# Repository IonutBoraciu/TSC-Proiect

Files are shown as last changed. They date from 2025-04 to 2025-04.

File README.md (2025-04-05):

# OpenBook, Boraciu Ionut-Sorin 335CA

# Description 

 OpenBook is an open-source, affordable e-book reader designed for mass production. The project focuses on accessibility, cost efficiency, and user control, providing a customizable reading experience with open hardware and software.

# Table of contents
1. [Description](#description)
2. [E-Book Reader Diagram](#e-book-reader-diagram)
3. [Bill of materials (BOM)](#bill-of-materials-bom)
4. [Hardware Functionality Description](#hardware-functionality-description)
5. [Estimated Power Consumption 🔋](#estimated-power-consumption-)
6. [Total estimated power consumtion ( assuming wifi active) 🔋](#total-estimated-power-consumtion--assuming-wifi-active-)
7. [Estimated battery life](#estimated-battery-life)
8. [ESP32-C6 Pin Usage](#esp32-c6-pin-usage)
9. [Pins explanation](#pins-explanation)
10. [Final Product](#final-product)

 # E-Book Reader Diagram

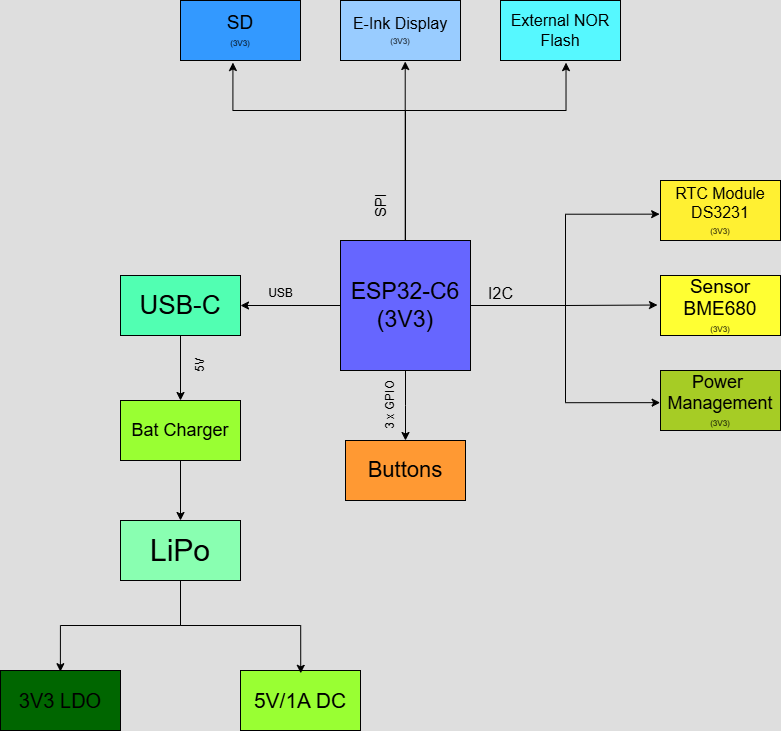
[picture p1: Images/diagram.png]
Diagram Image
 

 # Bill of materials (BOM)
 | 🛠 Component | 🔗 Link | 📄 Datasheet |
 |-------------|--------|------------|
 | 112A-TAAR-R03_ATTEND |[Comet](https://store.comet.srl.ro/Catalogue/Product/43497/) | [Datasheet](https://store.comet.bg/download-file.php?id=27596) |
 | 744043680IND | [Mouser](https://eu.mouser.com/ProductDetail/Wurth-Elektronik/744043680?qs=PGXP4M47uW6VkZq%252BkzjrHA%3D%3D) | [Datasheet](https://www.we-online.com/components/products/datasheet/744043680.pdf) |
 | ADAFRUIT_LEDCHIP | [SnapMagic](https://www.snapeda.com/parts/KP-1608SURCK/Kingbright/view-part/?ref=search&t=LED%200603) | [Datasheet](https://www.snapeda.com/parts/KP-1608SURCK/Kingbright/datasheet/) |
 | BD5229G-TR | [Component Search Engine](https://componentsearchengine.com/part-view/BD5229G-TR/ROHM%20Semiconductor) | [Datasheet](https://datasheet.datasheetarchive.com/originals/distributors/Datasheets_SAMA/f2b9741ef86007909f138d561a359946.pdf) |
 | BUTTON_CUSYOMV1 | [Panasonic](https://industry.panasonic.com/global/en/products/control/switch/light-touch/number/evqpuj02k) | [Datasheet](https://industry.panasonic.com/global/en/downloads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) |
 | CPH3225A | [SnapMagic](https://www.snapeda.com/parts/CPH3225A/Seiko+Instruments/view-part/?ref=eda) | [Datasheet](https://www.snapeda.com/parts/CPH3225A/Seiko%20Instruments/datasheet/) |
 | DS3231SN | [SnapMagic](https://www.snapeda.com/parts/DS3231SN%23/Analog+Devices/view-part/?ref=eda) | [Datasheet](https://www.snapeda.com/parts/DS3231SN%23/Analog%20Devices/datasheet/) |
 | EAGLE-LTSPICE_CC0402 | [Component Search Engine](https://componentsearchengine.com/part-view/CC0402MRX5R5BB106/YAGEO) | [Datasheet](https://componentsearchengine.com/Datasheets/2/CC0402MRX5R5BB106.pdf) |
 | ESP32-C6-WROOM-1-N8 | [SnapMagic](https://www.snapeda.com/parts/ESP32-C6-WROOM-1-N8/Espressif+Systems/view-part/?ref=eda) | [Datasheet](https://www.snapeda.com/parts/ESP32-C6-WROOM-1-N8/Espressif%20Systems/datasheet/) |
 | ESP32_WROVER_AVX | [Mouser](https://eu.mouser.com/ProductDetail/KYOCERA-AVX/SD0805S020S1R0?qs=jCA%252BPfw4LHbpkAoSnwrdjw%3D%3D) | [Datasheet](https://eu.mouser.com/datasheet/2/40/schottky-3165252.pdf) |
 | ESP32_WROVER_BME680_BME680 | [SnapMagic](https://www.snapeda.com/parts/BME680/Bosch/view-part/?welcome=home) | [Datasheet](https://www.snapeda.com/parts/BME680/Bosch%20Sensortec/datasheet/) |
 | ESP32_WROVER_EAGLE-LTSPICE_C | [Component Search Engine](https://componentsearchengine.com/part-view/CC0402MRX5R5BB106/YAGEO) | [Datasheet](https://componentsearchengine.com/Datasheets/2/CC0402MRX5R5BB106.pdf) |
 | ESP32_WROVER_EAGLE-LTSPICE_R | [Component Search Engine](https://componentsearchengine.com/part-view/R0402%201%25%20100%20K%20(RC0402FR-07100KL)/YAGEO) | [Datasheet](https://www.yageo.com/upload/media/product/products/datasheet/rchip/PYu-RC_Group_51_RoHS_L_12.pdf) |
 | ESP32_WROVER_SPARKFUN-DISCRETESEMI | [Component Search Engine](https://componentsearchengine.com/part-view/DMG2305UX-7/Diodes%20Incorporated) | [Datasheet](https://www.diodes.com//assets/Datasheets/DMG2305UX.pdf) |
 | ESP32_WROVER_SPARKFUN-IC-POWER_SOT23-5 | [Mouser](https://eu.mouser.com/ProductDetail/Microchip-Technology/MCP73831T-2ACI-OT?qs=yUQqVecv4qvbBQBGbHx0Mw%3D%3D) | [Datasheet](https://eu.mouser.com/datasheet/2/268/MCP73831_Family_Data_Sheet_DS20001984H-3441711.pdf) |
 | ESP32C6_VARISTORCN1812 | [Mouser](https://ro.mouser.com/ProductDetail/EPCOS-TDK/B72520T0350K062?qs=dEfas%2FXlABIszF52uu7vrg%3D%3D) | [Datasheet](https://www.tdk-electronics.tdk.com/inf/75/db/CTVS_14/Surge_protection_series.pdf) |
 | FH34SRJ24S05SH99 | [Component Search Engine](https://componentsearchengine.com/part-view/FH34SRJ-24S-0.5SH(99)/Hirose) | [Datasheet](https://www.hirose.com/en/product/document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) |
 | MAX17048G+T10 | [SnapMagic](https://www.snapeda.com/parts/MAX17048G+T10/Analog+Devices/view-part/?ref=eda) | [Datasheet](https://www.snapeda.com/parts/MAX17048G+T10/Analog%20Devices/datasheet/) |
 | MBR0530 | [Mouser](https://ro.mouser.com/ProductDetail/KYOCERA-AVX/SD0805S020S1R0?qs=jCA%252BPfw4LHbpkAoSnwrdjw%3D%3D) | [Datasheet](https://ro.mouser.com/datasheet/2/40/schottky-3165252.pdf) |
 | PGB1010603MR | [SnapMagic](https://www.snapeda.com/parts/PGB1010603MR/Littelfuse/view-part/?ref=eda) | [Datasheet](https://www.snapeda.com/parts/PGB1010603MR/Littelfuse%20Inc./datasheet/) |
 | QWIIC_CONNECTORJS | [Mouse](https://eu.mouser.com/ProductDetail/Adafruit/4208?qs=PzGy0jfpSMtbScLbr0L5dw%3D%3D) | [Datasheet](https://www.youtube.com/watch?v=Z6ACqvqwDWE) |
 | SAMACSYS_PARTS_USB4110-GF-A | [Component Search Engine](https://componentsearchengine.com/part-view/USB4110-GF-A/GCT%20(GLOBAL%20CONNECTOR%20TECHNOLOGY)) | [Datasheet](https://gct.co/files/drawings/usb4110.pdf) |
 | SI1308EDL-T1-GE3 | [Component Search Engine](https://componentsearchengine.com/part-view/SI1308EDL-T1-GE3/Vishay) | [Datasheet](https://componentsearchengine.com/Datasheets/1/SI1308EDL-T1-GE3.pdf) |
 | SJ | [GrabCAD](https://grabcad.com/library/solder-jumpers-1) | [Datasheet](https://www.youtube.com/watch?v=Z6ACqvqwDWE) |
 | USBLC6-2SC6Y | [SnapMagic](https://www.snapeda.com/parts/USBLC6-2SC6Y/STMicroelectronics/view-part/?ref=eda) | [Datasheet](https://www.snapeda.com/parts/USBLC6-2SC6Y/STMicroelectronics/datasheet/) |
 | W25Q512JVEIQ | [SnapMagic](https://www.snapeda.com/parts/W25Q512JVEIQ/Winbond+Electronics/view-part/?ref=eda) | [Datasheet](https://www.snapeda.com/parts/W25Q512JVEIQ/Winbond%20Electronics/datasheet/) |
 | XC6220A331MR-G | [Component Search Engine](https://componentsearchengine.com/part-view/XC6220A331MR-G/Torex) | [Datasheet](https://product.torexsemi.com/system/files/series/xc6220.pdf) |

# Hardware Functionality Description

### 1. Battery 🔋
 Model: CELLEVIA BATTERIES LP584174 <br>
 Specifications: 3.7V, 1800mAh  <br>
 Functionality: It is rechargeable battery, designed for portable electronic devices. It provides a stable power supply, high energy density, and a lightweight form factor. Ideal for IoT devices, wearables, embedded systems, and battery powered applications, it ensures reliable performance with a long cycle life.

 ### 2. ESP32-C6 📡
 Model: ESP32-C6-WROOM-1 <br>
 Specifications:
  * 2.4 GHz Wi-Fi 6 (802.11 ax)
  *  Bluetooth® 5 (LE) with Long Range support
  *  Zigbee and Thread(802.15.4) for low-power mesh networking  <br>
  
  Functionality: The ESP32-C6-WROOM-1 is the central controller of the project, handling all communication, control, and processing

  ### 3. E-Paper Display 📺
  Model: 7.5inch e-Paper V2 <br>
  Specifications: resolution : 800 x 480, weight ~ 44 g <br>
  Functionality: The 7.5-inch e-Paper V2 display provides a high contrast, low power visual output suitable for battery-powered applications. Unlike traditional displays, it retains content without power, making it ideal for low energy and always on applications.

 ### 4. BME688 🌡️
 Interface: I2C <br>
 Specifications:
  * Gas Sensor: Detects volatile organic compounds, carbon monoxide, hydrogen, and other gases
  * Humidity Sensor: 0–100% RH, accuracy ±3%
  * Temperature Sensor: -40°C to 85°C, accuracy ±0.5°C
  * Pressure Sensor: 300–1100 hPa, accuracy ±0.6 hPa <br>
  
 Functionality: The BME688 is an advanced environmental sensing module, providing real-time monitoring of air quality, humidity, temperature, and pressure.

 ### 5. SD Card 💾
 Interface: SPI <br>
 Functionality: it serves as expandable storage, allowing users to store a large collection of e-books, documents, and other files beyond the device's internal memory

 ### 6. RTC ⏰
 Interface: I2C <br>
 Functionality: A real-time clock (RTC) keeps track of the correct time and date, even when the device is off. It helps manage power saving features, timestamps activities like reading progress, supports reminder functions, updates time-sensitive content, and ensures proper synchronization with other devices or platforms.

 ### 7. MCP73831T ♻️🔋
 Interface: USB-C <br>
 Functionality: The MCP73831T is a compact lithium-ion and lithium-polymer battery charger IC. It features low power consumption, precharge and fast charge modes, thermal regulation, and overvoltage protection, making it ideal for portable devices.

 ### 8. External NOR Flash 64MB 🎞️
 Interface: SPI <br>
 Functionality:  non-volatile memory storage that provides 64MB of data storage. It's commonly used in embedded systems and devices for storing firmware, code, or other critical data, offering fast read speeds and reliable data retention even without power.

 ### 9. LDO Voltage Regulator ⚡
 Functionality: voltage regulator that provides a stable output voltage with minimal difference between the input and output voltages.

 ### 10. Test Pads 📝
 Functionality: deubbing and testing outputs from certain components.

 ### 11. Qwiic ✅
 Functionality: easy addition of modules through I2C and SPI.

 # Estimated Power Consumption 🔋

 ### 1. Battery (CELLEVIA BATTERIES LP584174) 🔋
  * Its power consumption depends on the load it is powering. The maximum discharge current would be around 1.8A (1800mAh)
### 2. ESP32-C6 📡
  * Wi-Fi transmission: ~200mA
  * Idle mode: ~50mA
  * Deep sleep: ~10mA
### 3. E-Paper Display 📺
  * During content update: ~30-50mA
  * Idle (static content): ~0mA (only power used for maintaining the display)
### 4. BME688 🌡️
 * Active sensing: ~2.7mA
 * Idle mode: ~0.5mA (depends on the sleep settings)
### 5. SD Card 💾
 * Typical: ~10-15 mA
### 6. RTC ⏰
* Active mode: 1- 2 mA
### 7. MCP73831T ♻️🔋
*  Minimal power consumption
### 8. External NOR Flash 64MB 🎞️
* Active read/write: ~10-20mA
* Idle: <1mA
### 9. LDO Voltage Regulator ⚡
 * Idle mode: ~1-10mA (depends on the output load)
### 10. Test Pads 📝
* Minimal power consumption, essentially 0mA unless active signals are being tested.
### 11. Qwiic ✅
* Active communication: ~5-10mA (depends on the connected module)

# Total estimated power consumtion ( assuming wifi active) 🔋

 | 🛠 Component | Power estimation 🔋
 |-------------|--------|
 | ESP32-C6 | 200 mA |
 | E-Paper Display | 50 mA |
 | BME688 | 2.7 mA |
 | SD Card | 15 mA |
 | RTC | 2 mA |
 | External NOR Flash | 20 mA |
 | LDO Voltage Regulator | 10 mA |
 | Qwiic | 10 mA |

Total = 200mA + 50mA + 2.7mA + 15mA + 2mA + 20mA + 10mA + 10mA = 309.7mA

# Estimated battery life

**Battery life = 1800 mAh / 309.7 mA = 5.81 hours**

# ESP32-C6 Pin Usage

## Power connections 🔋
* Pin 2 ( 3V3) - provides 3.3V to the ESP32-C6
* Ground ( bottom-right pin) - provides ground connection

## Reset and Boot 🔁
* Pin 3 ( Reset) - manual reset pin
* Pin 15 ( IO/BOOT) - boot mode selection, pulled down by a 10K resistor

## I2C 📡
* Pin 8 ( INT_RTC) - interrupt signal from RTC
* Pin 16 ( RTC_RST) - reset for RTC
* Pin 18 ( I2C_PW) - power enable signal for I2C devices
* Pin 20 ( SDA) - data line for I2C comms
* Pin 21 ( SCL) - clock line for I2C comms

## SPI 🛰️
* Pin 4 ( SS_SD) - slave select for SD card
* Pin 7 ( SCK) - Serial clock used for synchronizing SPI comms
* Pin 10 ( MOSI) - Master Out Slave In, sending data to components
* Pin 11 ( EPD_CS) - chip select for e-paper display
* Pin 12 ( FLASH_CS) - chip select for flash memory
* Pin 27 ( MISO)  - Master In Slave Out, used for reading data from components

## E-Paper Display Control Signals 🖥️
* Pin 5 ( EPD_DC) - data control for E-Paper Display
* Pin 19 ( EPD_3V3_C) - enable pin for EPD power
* Pin 21 ( EPD_RST) - reset pin for E-Paper Display
* Pin 26 ( EPD_BUSY) - indicates when E-Paper Display is busy

## USB 🔌
* Pin 13 ( USB_D-) + Pin 14 ( USB_D+) - differential data lines for USB comms

## UART 🔧
* Pin 24 ( RX) - UART receive pin
* Pin 25 ( TX) - UART transmit pin

## Others ⚙️
* Pin 23 ( IO_CHANGE)  - interrupt or status for external components

# Pins explanation

* SPI (Serial Peripheral Interface) is used for high speed comms with the Flash and E-Paper Display.
* I2C low speed comms with sensor ( RTC).
* UART pins ( TX, RX) debugging and external serial comms.
* Dedicated control pins ( EPD_BUSY, EPD_DC) ensure efficient E-Paper operation.

# Final Product
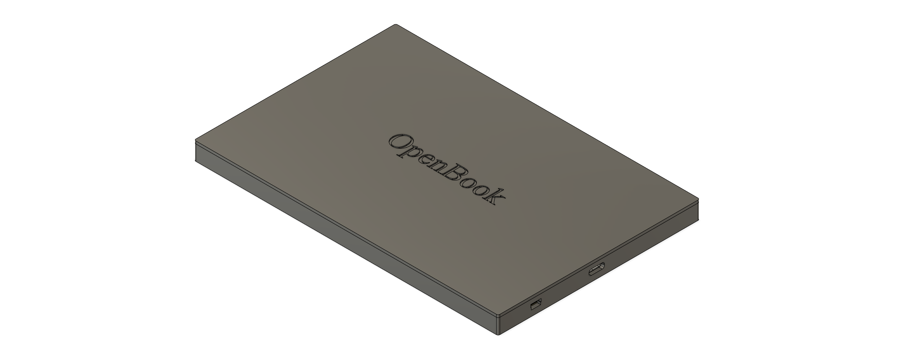
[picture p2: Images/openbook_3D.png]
3D Image
 
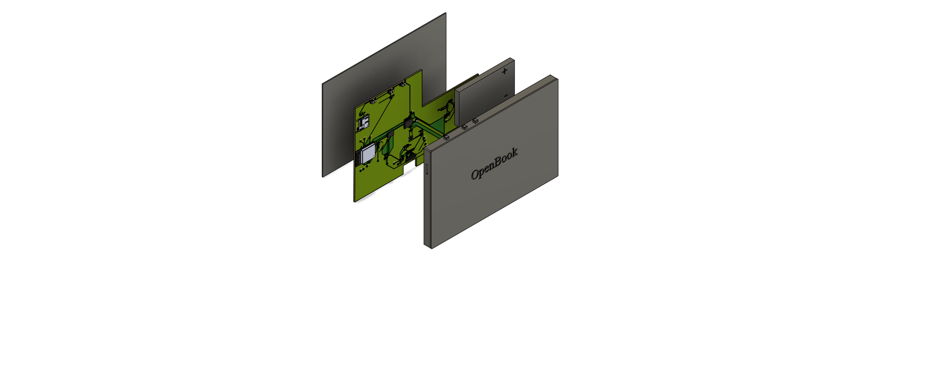
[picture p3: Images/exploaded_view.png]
Exploaded Image


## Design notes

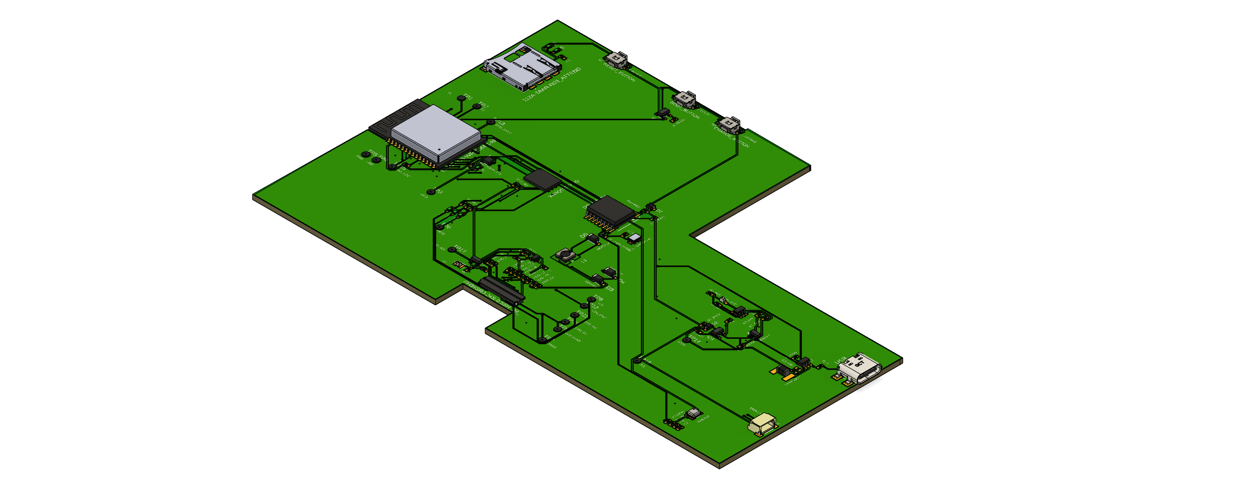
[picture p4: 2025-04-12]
Images/3D_board.png

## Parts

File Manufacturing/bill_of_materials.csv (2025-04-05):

Qty | Value | Device | Package | Parts | Description | ARROW_PART_NUMBER | ARROW_PRICE-STOCK | AVAILABILITY | CHECK_PRICES | COPYRIGHT | DESCRIPTION | HEIGHT | MANUFACTURER_NAME | MANUFACTURER_PART_NUMBER | MF | MFR_NAME | MOUSER_PART_NUMBER | MOUSER_PRICE-STOCK | MOUSER_TESTING_PART_NUMBER | MOUSER_TESTING_PRICE-STOCK | MP | PACKAGE | POPULARITY | PRICE | PROD_ID | PURCHASE-URL | SNAPEDA_LINK | SPICEMODEL | SPICEPREFIX | TP_SIGNAL_NAME | VALUE
1 |  | ADAFRUIT_LEDCHIP-LED0603 | ADAFRUIT_CHIP-LED0603 | CHG_LED | LED
1 |  | SJ | SJ | SJ1 | SMD solder JUMPER |  |  |  |  |  |  |  |  |  |  |  |  |  |  |  |  |  | 3
1 | 0.1uF/50V | ESP32_WROVER_EAGLE-LTSPICE_C | ESP32_WROVER_EAGLE-LTSPICE_C0402 | EPD_C5 | CAPACITOR, European symbol
1 | 0.47 | ESP32_WROVER_EAGLE-LTSPICE_R | ESP32_WROVER_EAGLE-LTSPICE_R0402 | R3 | RESISTOR, European symbol
1 | 100k | ESP32_WROVER_EAGLE-LTSPICE_R | ESP32_WROVER_EAGLE-LTSPICE_R0402 | R1_PWRUSB | RESISTOR, European symbol
1 | 100nF | EAGLE-LTSPICE_CC0402 | EAGLE-LTSPICE_C0402 | C6 | CAPACITOR, European symbol |  |  |  |  |  |  |  |  |  |  |  |  |  |  |  |  |  |  |  |  |  |  | NONE | C
7 | 100nF | ESP32_WROVER_EAGLE-LTSPICE_C | ESP32_WROVER_EAGLE-LTSPICE_C0402 | C2, C4, C4_USB, C8, C9, C10, C_DELAY | CAPACITOR, European symbol
1 | 100uF TANT | ESP32_WROVER_EAGLE-LTSPICE_C | ESP32_WROVER_EAGLE-LTSPICE_C0402 | C3 | CAPACITOR, European symbol
15 | 10K | ESP32_WROVER_EAGLE-LTSPICE_R | ESP32_WROVER_EAGLE-LTSPICE_R0402 | R1-PINH, R1_PINH1, R2-PINH, R2-PINH1, R4, R5, R6, R7, R8, R9, R10, R_BOOT, R_CHANGE, R_CL1, R_RESET | RESISTOR, European symbol
1 | 10k | ESP32_WROVER_EAGLE-LTSPICE_R | ESP32_WROVER_EAGLE-LTSPICE_R0402 | R1 | RESISTOR, European symbol
1 | 10uF | ESP32_WROVER_EAGLE-LTSPICE_C | ESP32_WROVER_EAGLE-LTSPICE_C0402 | C7 | CAPACITOR, European symbol
1 | 112A-TAAR-R03_ATTEND | 112A-TAAR-R03_ATTEND | 112ATAARR03ATTEND | J4 | Micro SD Card Socket, Push-Push Type, Top Mount, SMT, H=1.83mm, 10u |  |  |  |  |  | Micro SD Card Socket | Push-Push Type | Top Mount | SMT | H=1.83mm | 10u | 1.9mm | ATTEND | 112A-TAAR-R03 ATTEND
1 | 15 | ESP32_WROVER_EAGLE-LTSPICE_R | ESP32_WROVER_EAGLE-LTSPICE_R0402 | R_CAPACITOR | RESISTOR, European symbol
1 | 1uF | EAGLE-LTSPICE_CC0402 | EAGLE-LTSPICE_C0402 | C5 | CAPACITOR, European symbol |  |  |  |  |  |  |  |  |  |  |  |  |  |  |  |  |  |  |  |  |  |  | NONE | C
9 | 1uF/50V | ESP32_WROVER_EAGLE-LTSPICE_C | ESP32_WROVER_EAGLE-LTSPICE_C0402 | EPD_C1, EPD_C2, EPD_C6, EPD_C7, EPD_C8, EPD_C9, EPD_C10, EPD_C11, EPD_C12 | CAPACITOR, European symbol
1 | 2.2 | ESP32_WROVER_EAGLE-LTSPICE_R | ESP32_WROVER_EAGLE-LTSPICE_R0402 | R2 | RESISTOR, European symbol
1 | 200 | ESP32_WROVER_EAGLE-LTSPICE_R | ESP32_WROVER_EAGLE-LTSPICE_R0402 | R1_BAT | RESISTOR, European symbol
1 | 2k | ESP32_WROVER_EAGLE-LTSPICE_R | ESP32_WROVER_EAGLE-LTSPICE_R0402 | R2_BAT | RESISTOR, European symbol
5 | 4.7uF | ESP32_WROVER_EAGLE-LTSPICE_C | ESP32_WROVER_EAGLE-LTSPICE_C0402 | C1_BAT, C1_BAT1, C1_BAT2, C2_BAT, C5_USB | CAPACITOR, European symbol
1 | 4.7uF/25V | ESP32_WROVER_EAGLE-LTSPICE_C | ESP32_WROVER_EAGLE-LTSPICE_C0402 | C1 | CAPACITOR, European symbol
2 | 5k1 | ESP32_WROVER_EAGLE-LTSPICE_R | ESP32_WROVER_EAGLE-LTSPICE_R0402 | R2-USB, R_J2 | RESISTOR, European symbol
1 | 68uH | 744043680IND_4828-WE-TPC_WRE | IND_4828-WE-TPC_WRE | L1 |  |  |  |  |  | Copyright (C) 2024 Ultra Librarian. All rights reserved. |  |  |  | 744043680 |  | Wurth Electronics
1 | BD5229G-TR | BD5229G-TR | SOT95P280X125-5N | IC1 | Voltage Detector with Adjustable Delay Time: CMOS processes are utilized to develop high precision, low current consumption CMOS reset ICs that allow arbitrary setting of the delay time. The extensive lineup includes both Nch Open Drain and CMOS output types in a wide range of detection voltages (from 2.3V to 6.0V, in 0.1V steps), enabling selection of the ideal solution based on customer requirements. In addition, the entire series is of course both lead-free and RoHS-compliant. |  |  |  |  |  | Voltage Detector with Adjustable Delay Time: CMOS processes are utilized to develop high precision | low current consumption CMOS reset ICs that allow arbitrary setting of the delay time. The extensive lineup includes both Nch Open Drain and CMOS output types in a wide range of detection voltages (from 2.3V to 6.0V | in 0.1V steps) | enabling selection of the ideal solution based on customer requirements. In addition | the entire series is of course both lead-free and RoHS-compliant. | 1.25mm | ROHM Semiconductor | BD5229G-TR |  |  | 755-BD5229G-TR | https://www.mouser.co.uk/ProductDetail/ROHM-Semiconductor/BD5229G-TR?qs=4kLU8WoGk0vvnhrrYwdszw%3D%3D
1 | BME688 | ESP32_WROVER_BME680_BME680 | ESP32_WROVER_BME680_PSON80P300X300X100-8N | SENSOR2 | Integrated Environmental Unit |  |  | Unavailable |  |  | Integrated Environmental Unit |  |  |  | Bosch Sensortec |  |  |  |  |  | BME680 | LGA-8 Bosch Tools |  | None
1 | BOOT_BUTTON | BUTTON_CUSYOMV12_MYBUTTON | MYBUTTON | U$2
1 | CHANGE_BUTTON | BUTTON_CUSYOMV12_MYBUTTON | MYBUTTON | U$3
1 | CPH3225A | CPH3225A | CAPCP3225X100N | C10_SUPERCAP | Cap 0.011F 3.3V 1210 Flat Check availability |  |  | Not in stock | https://www.snapeda.com/parts/CPH3225A/Seiko+Instruments/view-part/?ref=eda |  | 11 mF (EDLC) Supercapacitor 3.3 V 1210 (3225 Metric) - - |  |  |  | Seiko Instruments |  |  |  |  |  | CPH3225A | 1210 Seiko |  | None |  | https://www.snapeda.com/api/url_track_click_mouser/?unipart_id=562593&manufacturer=Seiko Instruments&part_name=CPH3225A&search_term=None | https://www.snapeda.com/parts/CPH3225A/Seiko+Instruments/view-part/?ref=snap
1 | DS3231SN# | DS3231SN# | SOIC127P1032X265-16N | U3 | Real Time Clock Serial 16-Pin SOIC W T/R Check availability |  |  | In Stock | https://www.snapeda.com/parts/DS3231SN%23/Analog+Devices/view-part/?ref=eda |  | Extremely Accurate I²C-Integrated RTC/TCXO/Crystal |  |  |  | Analog Devices |  |  |  |  |  | DS3231SN# | SOIC-16 Maxim |  | None |  | https://www.snapeda.com/api/url_track_click_mouser/?unipart_id=99048&manufacturer=Analog Devices&part_name=DS3231SN#&search_term=None | https://www.snapeda.com/parts/DS3231SN%23/Analog+Devices/view-part/?ref=snap
1 | ESP32-C6-WROOM-1-N8 | ESP32-C6-WROOM-1-N8 | XCVR_ESP32-C6-WROOM-1-N8 | U2 | Check availability |  |  | In Stock | https://www.snapeda.com/parts/ESP32-C6-WROOM-1-N8/Espressif+Systems/view-part/?ref=eda |  | Multiprotocol Modules ESP32-C6 module | Wi-Fi 6 in 2.4 GHz band | Bluetooth 5 | Zigbee 3.0 and Thread. ESP34-WROOM Compatible - ENGINEERING SAMPLE |  |  |  | Espressif Systems |  |  |  |  |  | ESP32-C6-WROOM-1-N8 | None |  | None |  |  | https://www.snapeda.com/parts/ESP32-C6-WROOM-1-N8/Espressif+Systems/view-part/?ref=snap
1 | ESP32C6_VARISTORCN1812 | ESP32C6_VARISTORCN1812 | ESP32C6_VARISTOR_CT/CN1812 | PFMF.050.1 | VARISTOR |  |  |  |  |  |  |  |  |  |  |  |  |  |  |  |  |  | 0
2 | ESP32_WROVER_AVX---SD0805S020S1R0_AVX_SD0805S020S1R0_0_0 | ESP32_WROVER_AVX---SD0805S020S1R0_AVX_SD0805S020S1R0_0_0 | ESP32_WROVER_AVX---SD0805S020S1R0_AVX_SD0805S020S1R0_0 | D2, D7 | Schottky Barrier Rectifier Diode
2 | ESP32_WROVER_SPARKFUN-DISCRETESEMI_MOSFET_PCH | ESP32_WROVER_SPARKFUN-DISCRETESEMI_MOSFET_PCH | ESP32_WROVER_SPARKFUN-DISCRETESEMI_SOT23-3 | Q1, Q2 | P-channel MOSFETs
1 | ESP32_WROVER_SPARKFUN-IC-POWER_MCP73831 | ESP32_WROVER_SPARKFUN-IC-POWER_MCP73831 | ESP32_WROVER_SPARKFUN-IC-POWER_SOT23-5 | MCP73831 | MCP73831T Li-Ion, Li-Pol Controller |  |  |  |  |  |  |  |  |  |  |  |  |  |  |  |  |  |  |  | IC-09995
1 | FH34SRJ-24S-0.5SH_99_ | FH34SRJ-24S-0.5SH_99_ | FH34SRJ24S05SH99 | J1 | (0.50mm) Surface Mount, Right Angle |  |  |  |  |  | 24 Position FFC | FPC Connector Contacts | (0.50mm) Surface Mount | Right Angle | 1.1mm | Hirose | FH34SRJ-24S-0.5SH(99) |  |  | 798-FH34SRJ24S05SH99 | https://www.mouser.co.uk/ProductDetail/Hirose-Connector/FH34SRJ-24S-0.5SH99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
1 | MAX17048G+T10 | MAX17048G+T10 | SON50P200X200X80-9N | U4 | Check availability |  |  | In Stock | https://www.snapeda.com/parts/MAX17048G+T10/Analog+Devices/view-part/?ref=eda |  | 3µA 1-Cell/2-Cell Fuel Gauge with ModelGauge |  |  |  | Analog Devices |  |  |  |  |  | MAX17048G+T10 | TDFN-8 Maxim |  | None |  | https://www.snapeda.com/api/url_track_click_mouser/?unipart_id=329239&manufacturer=Analog Devices&part_name=MAX17048G+T10&search_term=None | https://www.snapeda.com/parts/MAX17048G+T10/Analog+Devices/view-part/?ref=snap
3 | MBR0530MY_MBR | MBR0530MY_MBR | SOD3716X135N | D3, D4, D5 | ON SEMICONDUCTOR - MBR0530 - DIODE, SCHOTTKY, 0.5A, 30V, SOD-123
6 | PGB1010603MRPGB1010603MR | PGB1010603MRPGB1010603MR | DIOC1608X36N | D6, D8, D9, D10, D11, D12 | Check availability
1 | QWIIC_RIGHT_ANGLE | QWIIC_CONNECTORJS-1MM | JST04_1MM_RA | J3 | SparkFun I2C Standard Qwiic Connector |  |  |  |  |  |  |  |  |  |  |  |  |  |  |  |  |  |  |  | CONN-13694 |  |  |  |  |  | QWIIC_RIGHT_ANGLE
1 | RESET_BUTTON | BUTTON_CUSYOMV12_MYBUTTON | MYBUTTON | U$1
1 | SAMACSYS_PARTS_USB4110-GF-A | SAMACSYS_PARTS_USB4110-GF-A | SAMACSYS_PARTS_USB4110GFA | J2 | CONN USB 2.0 TYPE-C R/A SMT |  |  |  |  |  | CONN USB 2.0 TYPE-C R/A SMT | 3.26mm | GCT (GLOBAL CONNECTOR TECHNOLOGY) | USB4110-GF-A |  |  | 640-USB4110-GF-A | https://www.mouser.co.uk/ProductDetail/GCT/USB4110-GF-A?qs=KUoIvG%2F9IlYiZvIXQjyJeA%3D%3D
1 | SI1308EDL-T1-GE3 | SI1308EDL-T1-GE3 | SOT65P210X110-3N | Q3 | MOSFET N-Ch 30V 1.5A TrenchFET SC70 Vishay Si1308EDL-T1-GE3 N-channel MOSFET Transistor, 1.5 A, 30 V, 3-Pin SC-70 |  |  | In Stock | https://www.snapeda.com/parts/SI1308EDL-T1-GE3/Vishay+Siliconix/view-part/?ref=eda |  | Si1308EDL-T1-GE3 N-channel MOSFET Transistor | 1.5 A | 30 V | 3-Pin SC-70 | Siliconix / Vishay SI1308EDL-T1-GE3 |  |  |  | Vishay Siliconix |  |  |  |  |  | SI1308EDL-T1-GE3 | SOT-323 Vishay Semiconductor |  | None |  | https://www.snapeda.com/api/url_track_click_mouser/?unipart_id=274603&manufacturer=Vishay Siliconix&part_name=SI1308EDL-T1-GE3&search_term=None | https://www.snapeda.com/parts/SI1308EDL-T1-GE3/Vishay+Siliconix/view-part/?ref=snap
1 | TP | TP | TP20R | TP17 | Test pad
16 | TPTP20R | TPTP20R | TP20R | TP1, TP2, TP3, TP4, TP5, TP6, TP7, TP8, TP9, TP10, TP11, TP12, TP13, TP14, TP15, TP16 | Test pad |  |  |  |  |  |  |  |  |  |  |  |  |  |  |  |  |  | 2
1 | USBLC6-2SC6Y | USBLC6-2SC6Y | SOT95P280X145-6N | D1 | Low Cap. ESD Protection Auto SOT-23-6 STMicroelectronics USBLC6-2SC6Y, Dual Uni-Directional TVS Diode Array, 6-Pin SOT-23 |  |  | In Stock | https://www.snapeda.com/parts/USBLC6-2SC6Y/STMicroelectronics/view-part/?ref=eda |  | 17V Clamp 5A (8/20µs) Ipp Tvs Diode Surface Mount SOT-23-6 |  |  |  | STMicroelectronics |  |  |  |  |  | USBLC6-2SC6Y | SOT-23-6 STMicroelectronics |  | None |  |  | https://www.snapeda.com/parts/USBLC6-2SC6Y/STMicroelectronics/view-part/?ref=snap
1 | W25Q512JVEIQ | W25Q512JVEIQ | SON127P600X800X80-9N | U1 | Check availability |  |  | In Stock | https://www.snapeda.com/parts/W25Q512JVEIQ/Winbond+Electronics/view-part/?ref=eda |  | FLASH - NOR Memory IC 512Mb (64M x 8) SPI - Quad I/O 133 MHz 8-WSON (8x6) |  |  |  | Winbond Electronics |  |  |  |  |  | W25Q512JVEIQ | Package |  | None |  |  | https://www.snapeda.com/parts/W25Q512JVEIQ/Winbond+Electronics/view-part/?ref=snap
1 | XC6220A331MR-G | XC6220A331MR-G | SOT95P280X120-5N | IC4 | LDO Voltage Regulators |  |  |  |  |  | LDO Voltage Regulators | 1.2mm | Torex | XC6220A331MR-G |  |  | 865-XC6220A331MR-G | https://www.mouser.co.uk/ProductDetail/Torex-Semiconductor/XC6220A331MR-G?qs=AsjdqWjXhJ8ZSWznL1J0gg%3D%3D

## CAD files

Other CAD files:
Mechanical/openbook_3D.f3z

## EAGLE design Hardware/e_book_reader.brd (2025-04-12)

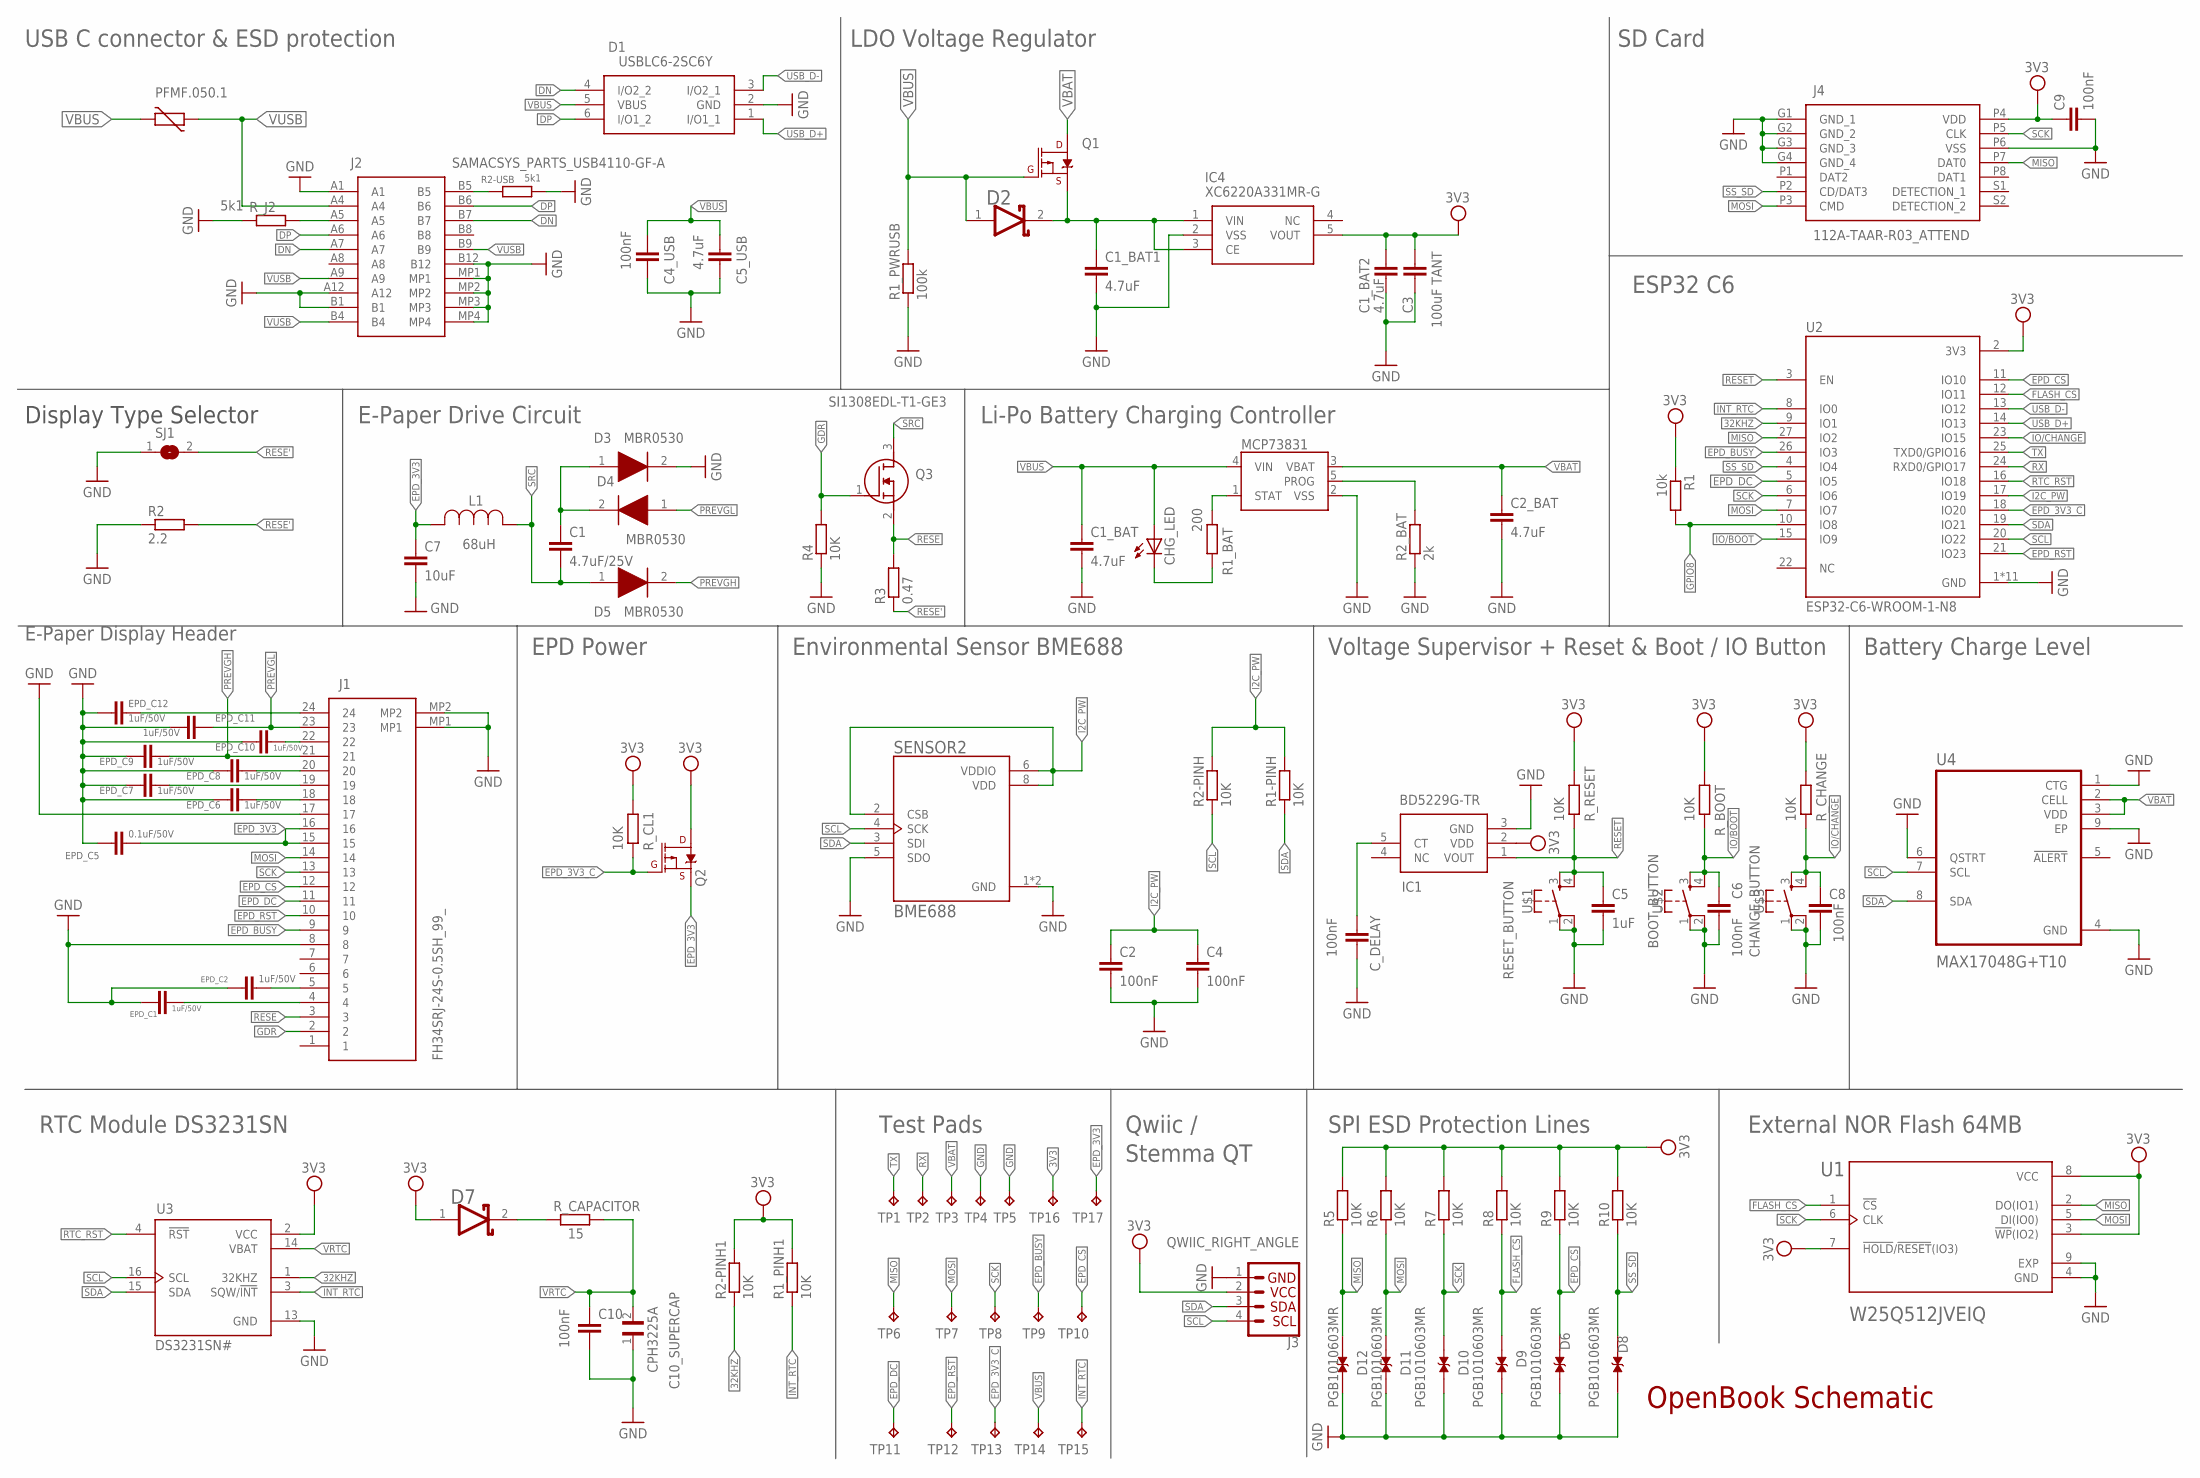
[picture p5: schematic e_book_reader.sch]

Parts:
C1: 4.7uF/25V; ESP32_WROVER_EAGLE-LTSPICE_C0402
C1_BAT, C1_BAT1, C1_BAT2, C2_BAT, C5_USB: 4.7uF; ESP32_WROVER_EAGLE-LTSPICE_C0402
C2, C4, C4_USB, C8, C9, C10: 100nF; ESP32_WROVER_EAGLE-LTSPICE_C0402
C3: 100uF TANT; ESP32_WROVER_EAGLE-LTSPICE_C0402
C5: 1uF; EAGLE-LTSPICE_C0402
C6: 100nF; EAGLE-LTSPICE_C0402
C7: 10uF; ESP32_WROVER_EAGLE-LTSPICE_C0402
C10_SUPERCAP: CPH3225A; CAPCP3225X100N
CHG_LED: ADAFRUIT_LEDCHIP-LED0603; ADAFRUIT_CHIP-LED0603
C_DELAY: 100nF; ESP32_WROVER_EAGLE-LTSPICE_C0402
D1: USBLC6-2SC6Y; SOT95P280X145-6N
D2, D7: ESP32_WROVER_AVX---SD0805S020S1R0_AVX_SD0805S020S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; ESP32_WROVER_AVX---SD0805S020S1R0_AVX_SD0805S020S1R0_0
D3, D4, D5: MBR0530; SOD3716X135N
D6, D8, D9, D10, D11, D12: PGB1010603MR; DIOC1608X36N
EPD_C1, EPD_C2, EPD_C6, EPD_C7, EPD_C8, EPD_C9, EPD_C10, EPD_C11, EPD_C12: 1uF/50V; ESP32_WROVER_EAGLE-LTSPICE_C0402
EPD_C5: 0.1uF/50V; ESP32_WROVER_EAGLE-LTSPICE_C0402
IC1: BD5229G-TR; SOT95P280X125-5N
IC4: XC6220A331MR-G; SOT95P280X120-5N
J1: FH34SRJ-24S-0.5SH_99_; FH34SRJ24S05SH99
J2: SAMACSYS_PARTS_USB4110-GF-A; SAMACSYS_PARTS_USB4110GFA
J3: QWIIC_RIGHT_ANGLE; JST04_1MM_RA
J4: 112A-TAAR-R03_ATTEND; 112ATAARR03ATTEND
L1: 68uH; IND_4828-WE-TPC_WRE
MCP73831: ESP32_WROVER_SPARKFUN-IC-POWER_MCP73831; ESP32_WROVER_SPARKFUN-IC-POWER_SOT23-5
PFMF.050.1: ESP32C6_VARISTORCN1812; ESP32C6_VARISTOR_CT/CN1812
Q1, Q2: ESP32_WROVER_SPARKFUN-DISCRETESEMI_MOSFET_PCH; ESP32_WROVER_SPARKFUN-DISCRETESEMI_SOT23-3
Q3: SI1308EDL-T1-GE3; SOT65P210X110-3N
R1: 10k; ESP32_WROVER_EAGLE-LTSPICE_R0402
R1-PINH, R1_PINH1, R2-PINH, R2-PINH1, R4, R5, R6, R7, R8, R9, R10: 10K; ESP32_WROVER_EAGLE-LTSPICE_R0402
R1_BAT: 200; ESP32_WROVER_EAGLE-LTSPICE_R0402
R1_PWRUSB: 100k; ESP32_WROVER_EAGLE-LTSPICE_R0402
R2: 2.2; ESP32_WROVER_EAGLE-LTSPICE_R0402
R2-USB: 5k1; ESP32_WROVER_EAGLE-LTSPICE_R0402
R2_BAT: 2k; ESP32_WROVER_EAGLE-LTSPICE_R0402
R3: 0.47; ESP32_WROVER_EAGLE-LTSPICE_R0402
R_BOOT: 10K; ESP32_WROVER_EAGLE-LTSPICE_R0402
R_CAPACITOR: 15; ESP32_WROVER_EAGLE-LTSPICE_R0402
R_CHANGE: 10K; ESP32_WROVER_EAGLE-LTSPICE_R0402
R_CL1: 10K; ESP32_WROVER_EAGLE-LTSPICE_R0402
R_J2: 5k1; ESP32_WROVER_EAGLE-LTSPICE_R0402
R_RESET: 10K; ESP32_WROVER_EAGLE-LTSPICE_R0402
SENSOR2: BME688; ESP32_WROVER_BME680_PSON80P300X300X100-8N
SJ1: SJ
TP1, TP2, TP3, TP4, TP5, TP6, TP7, TP8, TP9, TP10, TP11, TP12, TP13, TP14, TP15, TP16: TPTP20R; TP20R
TP17: TP; TP20R
U1: W25Q512JVEIQ; SON127P600X800X80-9N
U2: ESP32-C6-WROOM-1-N8; XCVR_ESP32-C6-WROOM-1-N8
U3: DS3231SN#; SOIC127P1032X265-16N
U4: MAX17048G+T10; SON50P200X200X80-9N
U$1: RESET_BUTTON; MYBUTTON
U$2: BOOT_BUTTON; MYBUTTON
U$3: CHANGE_BUTTON; MYBUTTON

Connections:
3V3: C1_BAT2.1, C3.1, C9.1, D7.1 (ANODE), IC1.2 (VDD), IC4.5 (VOUT), J3.2, J4.P4 (VDD), Q2.1 (D), R1.1, R1_PINH1.2, R2-PINH1.2, R5.2, R6.2, R7.2, R8.2, R9.2, R10.2, R_BOOT.2, R_CHANGE.2, R_CL1.2, R_RESET.2, TP16.TP, U1.3 (!WP!(IO2)), U1.7 (!HOLD!/!RESET!(IO3)), U1.8 (VCC), U2.2 (3V3), U3.2 (VCC)
32KHZ: R2-PINH1.1, U2.9 (IO1), U3.1 (32KHZ)
DN: D1.4 (I/O2_2), J2.A7, J2.B7
DP: D1.6 (I/O1_2), J2.A6, J2.B6
EPD_3V3: C7.1, EPD_C5.1, J1.15, J1.16, L1.2, Q2.3 (S), TP17.TP
EPD_3V3_C: Q2.2 (G), R_CL1.1, TP13.TP, U2.18 (IO20)
EPD_BUSY: J1.9, TP9.TP, U2.26 (IO3)
EPD_CS: D6.1, J1.12, R9.1, TP10.TP, U2.11 (IO10)
EPD_DC: J1.11, TP11.TP, U2.5 (IO5)
EPD_RST: J1.10, TP12.TP, U2.21 (IO23)
FLASH_CS: D9.1, R8.1, U1.1 (!CS), U2.12 (IO11)
GDR: J1.2, Q3.1 (G), R4.2
GND: C1_BAT.2, C1_BAT1.2, C1_BAT2.2, C2.2, C2_BAT.2, C3.2, C4.2, C4_USB.2, C5.2, C5_USB.2, C6.2, C7.2, C8.2, C9.2, C10.2, C10_SUPERCAP.1, C_DELAY.2, D1.2 (GND), D3.2 (K), D6.2, D8.2, D9.2, D10.2, D11.2, D12.2, EPD_C1.2, EPD_C2.2, EPD_C5.2, EPD_C6.2, EPD_C7.2, EPD_C8.2, EPD_C9.2, EPD_C10.2, EPD_C11.2, EPD_C12.2, IC1.3 (GND), IC4.2 (VSS), J1.8, J1.17, J1.MP1, J1.MP2, J2.A1, J2.A12, J2.B1, J2.B12, J2.MP1, J2.MP2, J2.MP3, J2.MP4, J3.1, J4.G1 (GND_1), J4.G2 (GND_2), J4.G3 (GND_3), J4.G4 (GND_4), J4.P6 (VSS), MCP73831.2 (VSS), R1_PWRUSB.1, R2.1, R2-USB.2, R2_BAT.1, R4.1, R_J2.1, SENSOR2.1 (GND), SENSOR2.5 (SDO), SENSOR2.7 (GND), SJ1.1, TP4.TP, TP5.TP, U1.4 (GND), U1.9 (EXP), U2.1 (GND), U2.28 (GND), U2.29_1 (GND), U2.29_2 (GND), U2.29_3 (GND), U2.29_4 (GND), U2.29_5 (GND), U2.29_6 (GND), U2.29_7 (GND), U2.29_8 (GND), U2.29_9 (GND), U3.13 (GND), U4.1 (CTG), U4.4 (GND), U4.6 (QSTRT), U4.9 (EP), U$1.1, U$1.2, U$2.1, U$2.2, U$3.1, U$3.2
GPIO8: R1.2, U2.10 (IO8)
I2C_PW: C2.1, C4.1, R1-PINH.2, R2-PINH.2, SENSOR2.2 (CSB), SENSOR2.6 (VDDIO), SENSOR2.8 (VDD), U2.17 (IO19)
INT_RTC: R1_PINH1.1, TP15.TP, U2.8 (IO0), U3.3 (SQW/!INT)
IO/BOOT: C6.1, R_BOOT.1, U2.15 (IO9), U$2.3, U$2.4
IO/CHANGE: C8.1, R_CHANGE.1, U2.23 (IO15), U$3.3, U$3.4
MISO: D12.1, J4.P7 (DAT0), R5.1, TP6.TP, U1.2 (DO(IO1)), U2.27 (IO2)
MOSI: D11.1, J1.14, J4.P3 (CMD), R6.1, TP7.TP, U1.5 (DI(IO0)), U2.7 (IO7)
unnamed: J2.A5, R_J2.2
unnamed: MCP73831.1 (STAT), R1_BAT.2
unnamed: J2.B5, R2-USB.1
unnamed: C1_BAT1.1, D2.2 (CATHODE), IC4.1 (VIN), IC4.3 (CE), Q1.3 (S)
unnamed: C1.1, D3.1 (A), D4.2 (K)
unnamed: CHG_LED.C, R1_BAT.1
unnamed: MCP73831.5 (PROG), R2_BAT.2
unnamed: EPD_C1.1, J1.4
unnamed: EPD_C6.1, J1.18
unnamed: EPD_C2.1, J1.5
unnamed: EPD_C7.1, J1.19
unnamed: EPD_C8.1, J1.20
unnamed: EPD_C10.1, J1.22
unnamed: EPD_C12.1, J1.24
unnamed: C_DELAY.1, IC1.5 (CT)
unnamed: D7.2 (CATHODE), R_CAPACITOR.1
PREVGH: D5.2 (K), EPD_C9.1, J1.21
PREVGL: D4.1 (A), EPD_C11.1, J1.23
RESE: J1.3, Q3.2 (S), R3.2
RESE': R2.2, R3.1, SJ1.2
RESET: C5.1, IC1.1 (VOUT), R_RESET.1, U2.3 (EN), U$1.3, U$1.4
RTC_RST: U2.16 (IO18), U3.4 (!RST)
RX: TP2.TP, U2.24 (RXD0/GPIO17)
SCK: D10.1, J1.13, J4.P5 (CLK), R7.1, TP8.TP, U1.6 (CLK), U2.6 (IO6)
SCL: J3.4, R2-PINH.1, SENSOR2.4 (SCK), U2.20 (IO22), U3.16 (SCL), U4.7 (SCL)
SDA: J3.3, R1-PINH.1, SENSOR2.3 (SDI), U2.19 (IO21), U3.15 (SDA), U4.8 (SDA)
SRC: C1.2, D5.1 (A), L1.1, Q3.3 (D)
SS_SD: D8.1, J4.P2 (CD/DAT3), R10.1, U2.4 (IO4)
TX: TP1.TP, U2.25 (TXD0/GPIO16)
USB_D+: D1.1 (I/O1_1), U2.14 (IO13)
USB_D-: D1.3 (I/O2_1), U2.13 (IO12)
VBAT: C2_BAT.1, MCP73831.3 (VBAT), Q1.1 (D), TP3.TP, U4.2 (CELL), U4.3 (VDD)
VBUS: C1_BAT.1, C4_USB.1, C5_USB.1, CHG_LED.A, D1.5 (VBUS), D2.1 (ANODE), MCP73831.4 (VIN), PFMF.050.1.2, Q1.2 (G), R1_PWRUSB.2, TP14.TP
VRTC: C10.1, C10_SUPERCAP.2, R_CAPACITOR.2, U3.14 (VBAT)
VUSB: J2.A4, J2.A9, J2.B4, J2.B9, PFMF.050.1.1

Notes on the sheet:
USB C connector & ESD protection
LDO Voltage Regulator
SD Card
Display Type Selector
E-Paper Drive Circuit
Li-Po Battery Charging Controller
ESP32 C6
E-Paper Display Header
EPD Power
Environmental Sensor BME688
Voltage Supervisor + Reset & Boot / IO Button
Battery Charge Level
RTC Module DS3231SN
Test Pads
Qwiic /
Stemma QT
SPI ESD Protection Lines
OpenBook Schematic
External NOR Flash 64MB

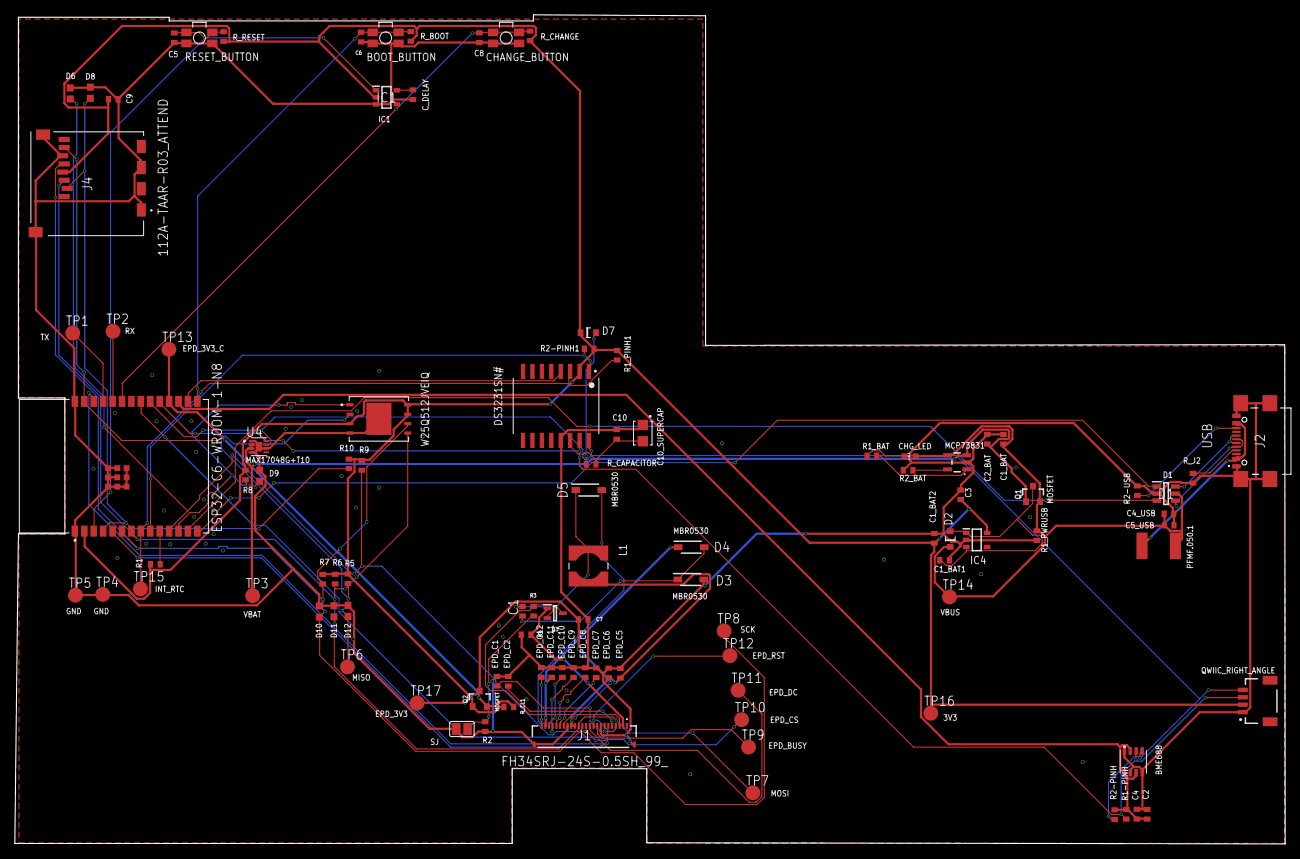
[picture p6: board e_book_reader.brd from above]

Board: 2 copper layers, 171.3 x 111.8 mm, 103 parts (0 on the bottom side), 55 nets.

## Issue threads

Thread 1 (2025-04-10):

Lipsă decupaj antenă

rafaelchitan, 2025-04-10:
Pe pcb, ar trebui să decupezi plăcuța ca să fie antena în exterior

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

IonutBoraciu, 2025-04-12:
Fixed!

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

Closed 2025-04-15.

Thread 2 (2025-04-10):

Denumiri dubioase la componente

rafaelchitan, 2025-04-10:
Ai câteva denumiri în schematic care pare că s-au dublat cumva și ies puțin din grid

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

IonutBoraciu, 2025-04-12:
Fixed! Imi salvasem cu nume dubioase componentele 3D

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

Closed 2025-04-15.

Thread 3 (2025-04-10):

Lipsa grid separare componente în schematic

rafaelchitan, 2025-04-10:
Ai putea să pui și gridurile pe layerul de info la schematic ca să se separe mai clar fiecare componentă

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

IonutBoraciu, 2025-04-12:
Fixed! Am adaugat separatorii pe layer-ul info

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

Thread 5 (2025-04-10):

Lipsa denumiri TP

rafaelchitan, 2025-04-10:
Ar trebui sa fie prezente pe placuta si denumirile TP-urilor(GND etc.). Ca sa faci asta, poti amplasa Text pe layerul Silkscreen al PCB-ului, iar apoi va aparea si pe modelul 3D.

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

IonutBoraciu, 2025-04-12:
Fixed! Am amplasat denumirile pe layer-ul 21 ( silkscreen top)

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

Closed 2025-04-15.

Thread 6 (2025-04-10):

Amplasare denumiri componente pe Silkscreen

rafaelchitan, 2025-04-10:
Ar trebui să ai toate denumirile componentelor pe Silkscreen pe PCB ca sa apara si pe placuta. Poti muta toate denumirile pe acel layer, iar apoi se vor vedea si dupa un push pe 3D.

IonutBoraciu, 2025-04-12:
Fixed! Ti-am urmat sfatul si am mutat denumirile pe silkscreen

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

Closed 2025-04-15.

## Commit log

2025-04-04 added board and schematic
    [e_book_reader.brd, e_book_reader.sch]
2025-04-04 Finished BOM
2025-04-04 added estimated power consumtion
2025-04-05 added CPL file
    [pick_and_place.csv]
2025-04-05 added bill of materials
    [bill_of_materials.csv]
2025-04-05 added gerbers arhive
2025-04-12 fixed issues
    [e_book_reader.brd, e_book_reader.sch]
2025-04-12 updated photo of 3D board

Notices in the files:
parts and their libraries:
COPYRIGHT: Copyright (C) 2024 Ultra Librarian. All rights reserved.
